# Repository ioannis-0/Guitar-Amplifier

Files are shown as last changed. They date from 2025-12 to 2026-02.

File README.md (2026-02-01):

### **Personal Project: Guitar Amplifier**
For this project, Ioannis and Daniel collaborated to design a guitar amplifier. Kicad was used to create a printed circuit board (PCB) compatible with an electric guitar to amplify its output volume.

This project is made up of two phases, with the first one being the **Creation of the PCB**  and the second being the **Testing** phase.

**Creation of the PCB:** Creation of the guitar amplifier PCB was done using KiCad. During this period, issues occured specifically concerning component selection. The components of an operational amplifier, power barrel connector, audio jack, and potentiometer were the main issues that arose. This issue was resolved through thorough research to identify components most compatible with our design goals: 

Operational amplifier = TL072 Lo/Noise 2XJFET Op. Amplifier (https://www.altronics.com.au/p/z2872-tl072-lo-noise-2xjfet-op-amplifier/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)

Power barrel connector = DCJ200-10-A-K1-K (https://www.digikey.com/en/products/detail/gct/DCJ200-10-A-K1-K/9859579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)

Audio jack = RJ3VM (https://www.mouser.com/ProductDetail/REAN/RJ3VM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)

Potentiometer = TC33X-2-103E (https://www.digikey.com/en/products/detail/bourns-inc/TC33X-2-103E/612858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)

After using these components a DRC (Design Rule Checking) was ran, the results showing no errors.

<ins> This is the KiCad file for the PCB: </ins>          
https://github.com/ioannis-0/Guitar-Amplifier/tree/main/Final%20personal%20project

<ins> Image of the PCB on KiCad: </ins>  
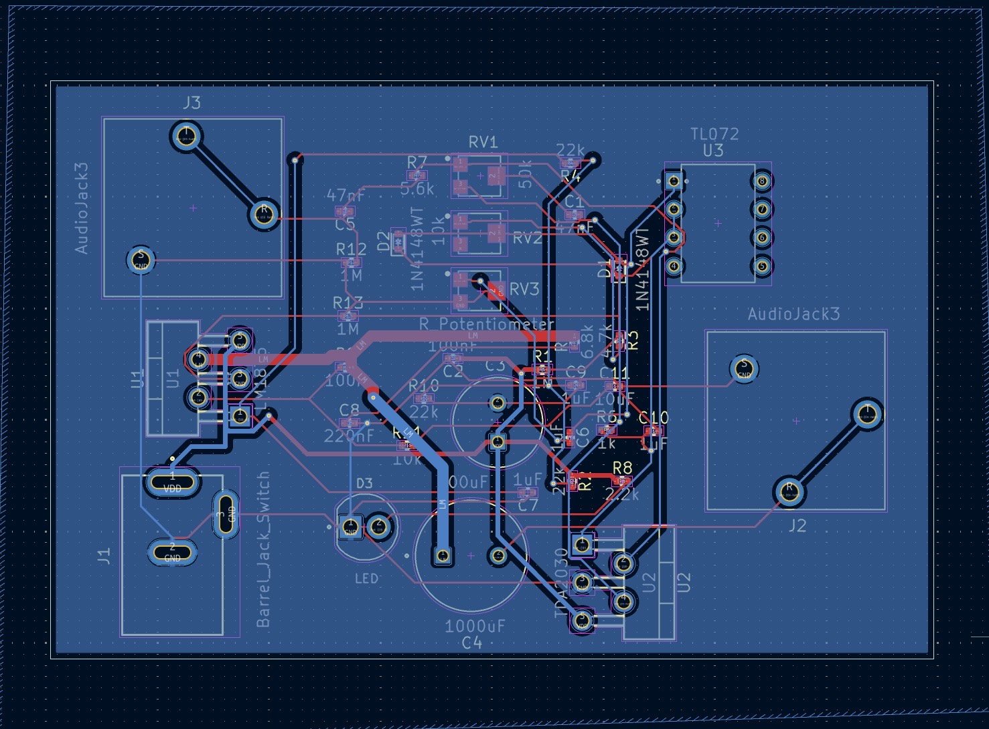
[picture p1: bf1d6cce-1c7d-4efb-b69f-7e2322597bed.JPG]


**Testing:** The PCB was tested on an electric guitar (Squier Sonic Stratocaster). The testing we conducted on this electric guitar was a success, as we were able to increase the volume output of the guitar using the PCB we had created. As no serious problems occurred during the testing phase. As the only issue that occurred was during the soldering process we had to modify the audio jack in order for it to work with the PCB, as the modificatiion was just altering the connect point with the PCB and we did that by using lead.

<ins> Images of the physical PCB: </ins>  
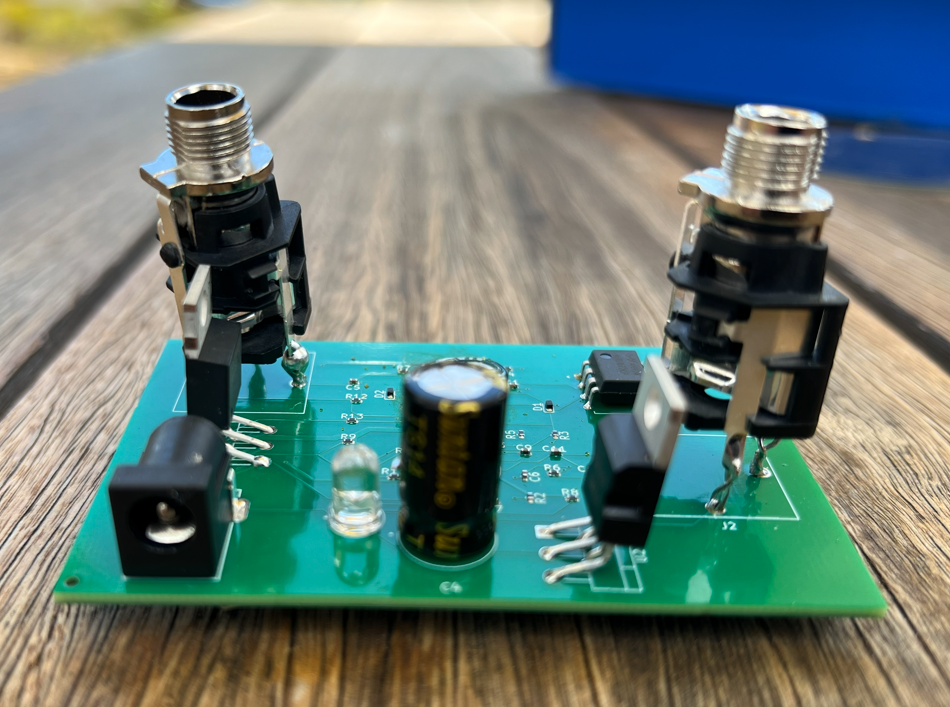
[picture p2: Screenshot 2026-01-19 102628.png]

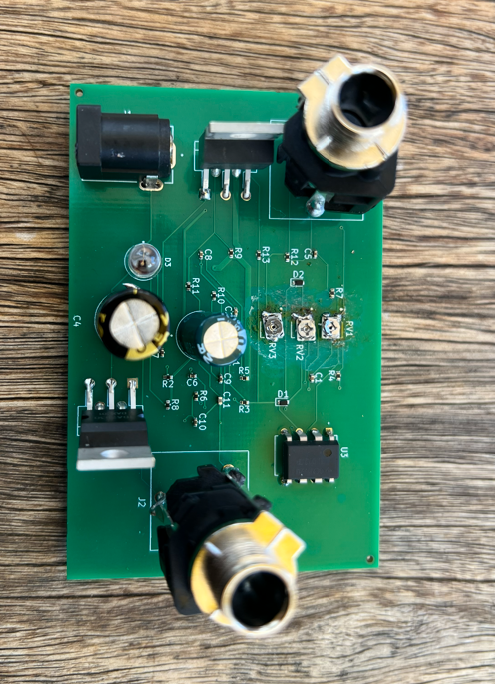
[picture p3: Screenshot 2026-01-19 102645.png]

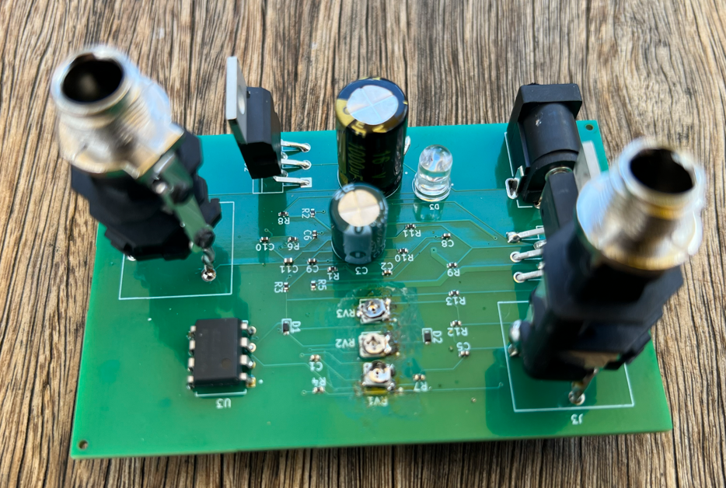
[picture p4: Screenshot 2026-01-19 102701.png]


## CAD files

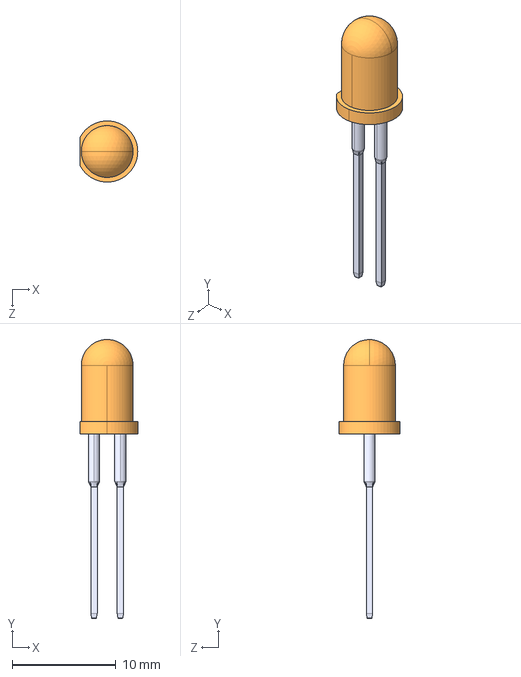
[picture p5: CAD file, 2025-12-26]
Final personal project/guitar_amp_proj/guitar_amp/L08R5000Q1/L08R5000Q1.step
5.55 x 26.9 x 5.90 mm

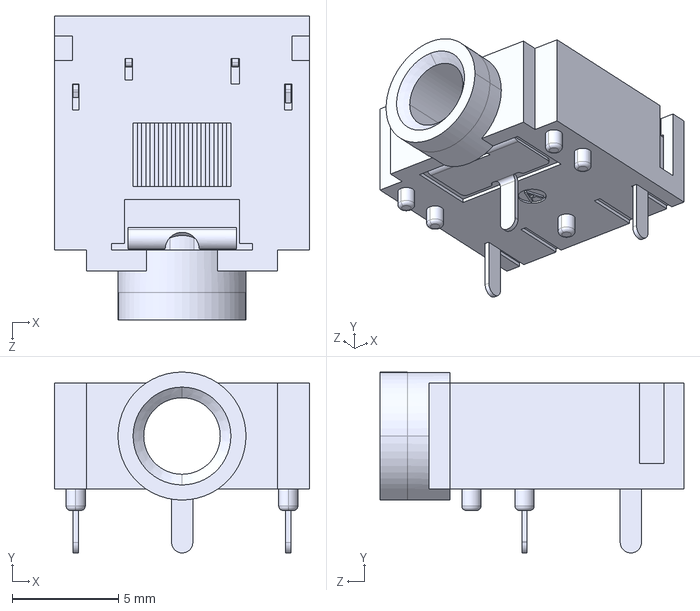
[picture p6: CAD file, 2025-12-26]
Final personal project/guitar_amp_proj/guitar_amp/SJ1-3523N/SJ1-3523N.step
12.0 x 8.51 x 14.3 mm

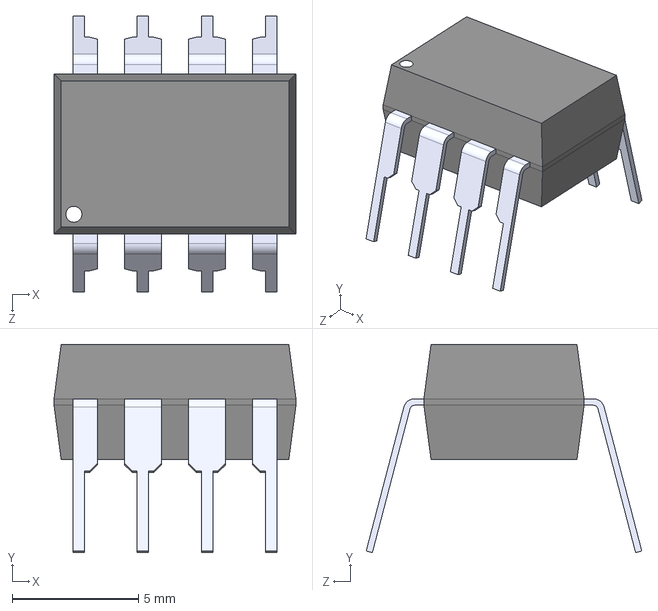
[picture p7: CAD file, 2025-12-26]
Final personal project/guitar_amp_proj/guitar_amp/TL072/TL072.step
9.59 x 8.25 x 10.9 mm

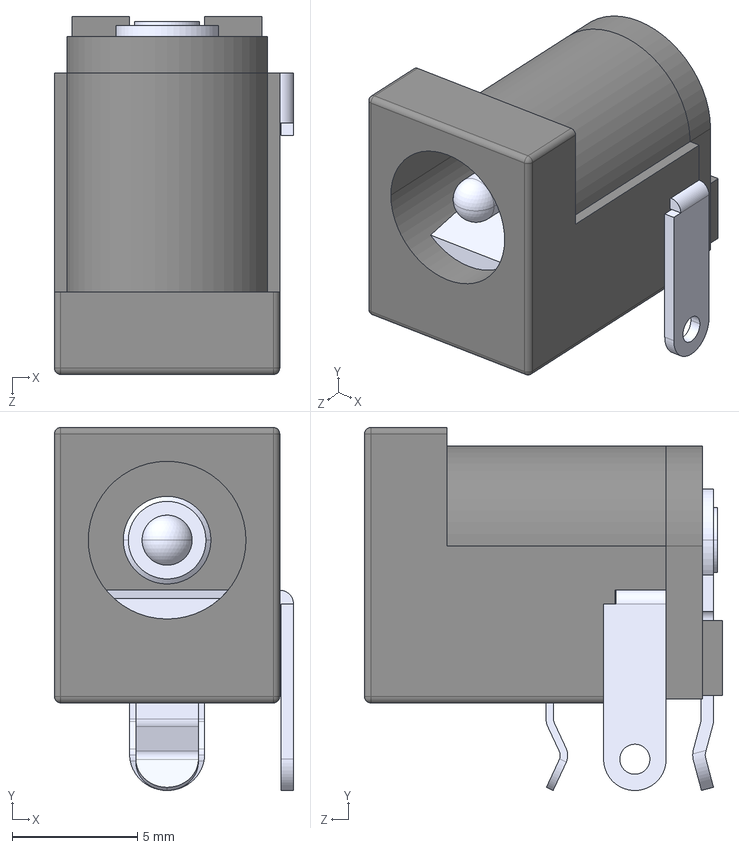
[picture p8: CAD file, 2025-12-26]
Final personal project/DCJ200-10-A-XX-K_REVA.step
9.55 x 14.5 x 14.3 mm

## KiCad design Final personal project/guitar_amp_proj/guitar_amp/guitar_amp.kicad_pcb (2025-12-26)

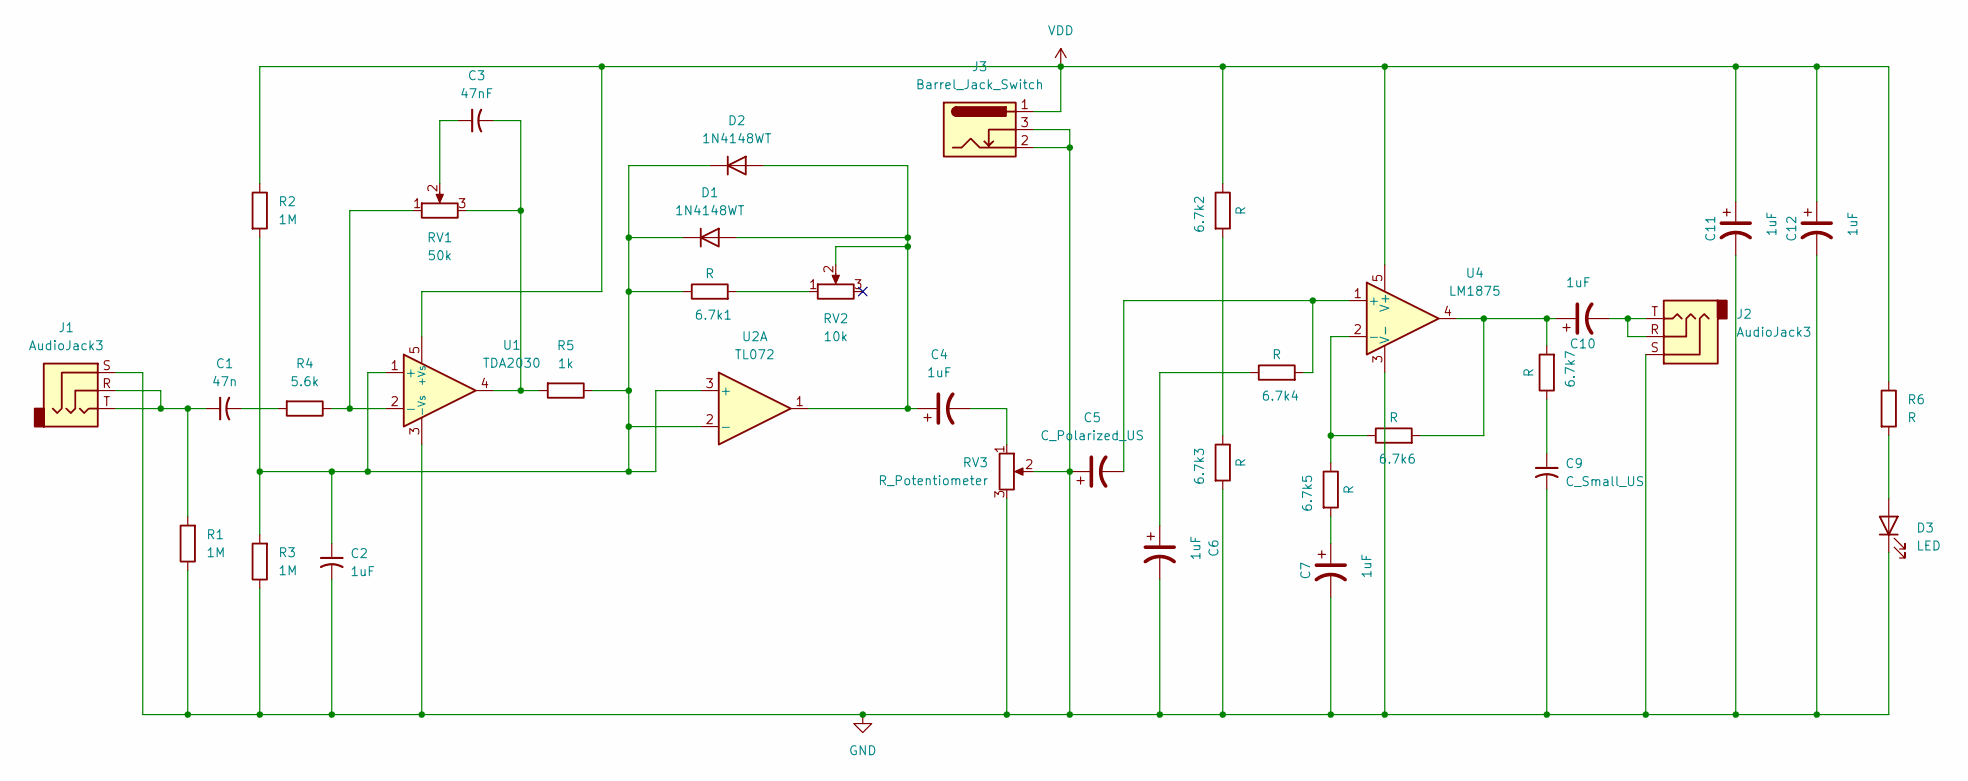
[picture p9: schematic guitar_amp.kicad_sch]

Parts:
6.7k1, 6.7k2, 6.7k3, 6.7k4, 6.7k5, 6.7k6, 6.7k7: R; C_0402_1005Metric
C1: 47n; C_0402_1005Metric
C2, C4, C6, C7, C10, C11, C12: 1uF; C_0402_1005Metric
C3: 47nF; C_0402_1005Metric
C5: C_Polarized_US; C_0402_1005Metric
C9: C_Small_US; C_0402_1005Metric
D1, D2: 1N4148WT; D_SOD-523
D3: LED; LEDRD254W57D500H1070
J1, J2: AudioJack3; REAN_RJ3VM
J3: Barrel_Jack_Switch; GCT_DCJ200-10-A-XX-K_REVA
R1, R2, R3: 1M; C_0402_1005Metric
R4: 5.6k; C_0402_1005Metric
R5: 1k; C_0402_1005Metric
R6: R; C_0402_1005Metric
RV1: 50k; TRIM_TC33X-2-103E
RV2: 10k; TRIM_TC33X-2-103E
RV3: R_Potentiometer; TRIM_TC33X-2-103E
U1: TDA2030; TO-220-5_P3.4x3.7mm_StaggerOdd_Lead3.8mm_Vertical
U2: TL072; DIP794W45P254L1060H508Q8
U4: LM1875; TO-220-5_P3.4x3.7mm_StaggerOdd_Lead3.8mm_Vertical

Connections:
GND: 6.7k3.2, C2.2, C5.1, C6.2, C7.2, C9.2, C11.2, C12.2, D3.1 (K), J1.S, J2.S, J3.2, J3.3, R1.1, R3.1, RV3.2, RV3.3, U1.3 (-Vs), U4.3 (V-)
unnamed: 6.7k1.2, RV2.1
unnamed: 6.7k2.2, 6.7k3.1
unnamed: 6.7k4.1, C6.1
unnamed: 6.7k5.2, C7.1
unnamed: 6.7k6.2, 6.7k7.2, C10.1, U4.4
unnamed: 6.7k7.1, C9.1
unnamed: C1.1, J1.R, J1.T, R1.2
unnamed: C1.2, R4.2
unnamed: C3.1, RV1.2
unnamed: C3.2, R5.2, RV1.3, U1.4
unnamed: C4.2, RV3.1
unnamed: C10.2, J2.R, J2.T
unnamed: C4.1, D1.2 (A), D2.2 (A), RV2.2, U2.1
unnamed: 6.7k1.1, C2.1, D1.1 (K), D2.1 (K), R2.2, R3.2, R5.1, U1.1 (+), U2.2 (-), U2.3 (+)
unnamed: D3.2 (A), R6.2
unnamed: R4.1, RV1.1, U1.2 (-)
unnamed: 6.7k4.2, C5.2, U4.1 (+)
unnamed: 6.7k5.1, 6.7k6.1, U4.2 (-)
VDD: 6.7k2.1, C11.1, C12.1, J3.1, R2.1, R6.1, U1.5 (+Vs), U4.5 (V+)

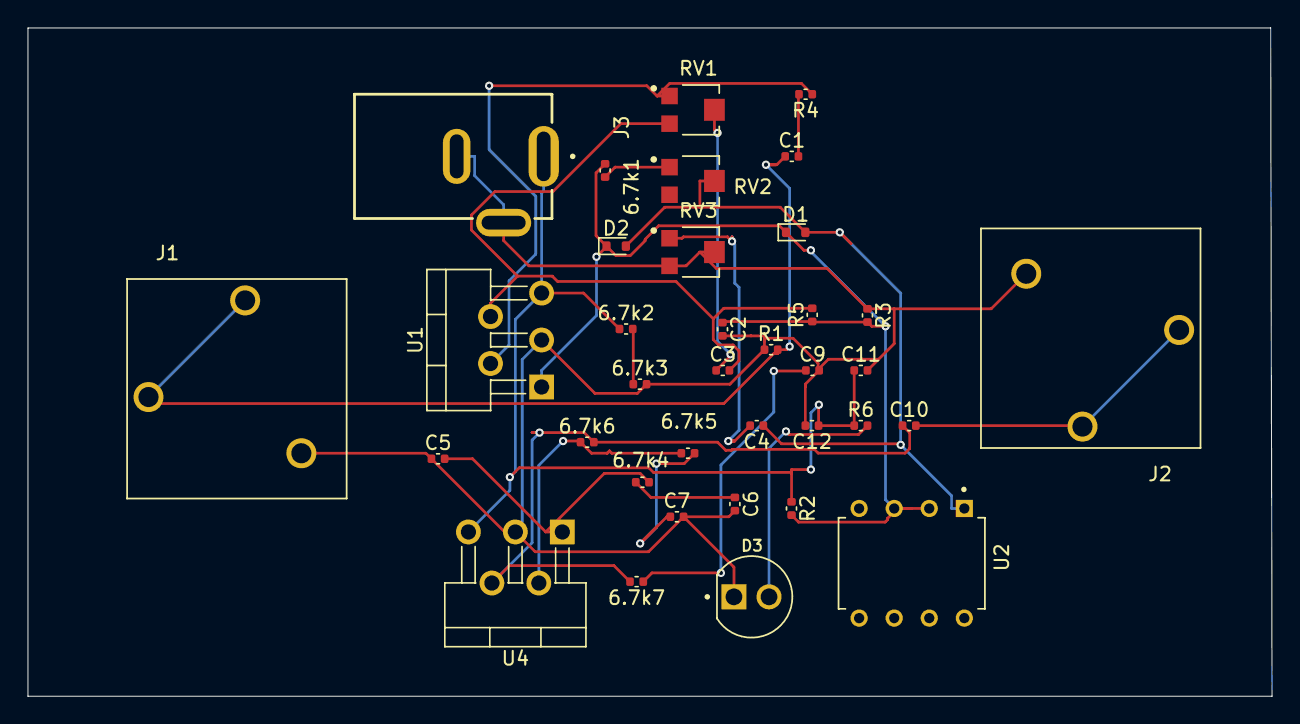
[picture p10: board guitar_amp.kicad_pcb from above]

Board: 2 copper layers, 90.1 x 48.4 mm, 36 parts (0 on the bottom side), 20 nets.

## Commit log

2025-12-26 Add files via upload
    here u go
    [DCJ200-10-A-XX-K_REVA.step, L08R5000Q1.step, SJ1-3523N.step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]
2025-12-26 PCB KiCad
